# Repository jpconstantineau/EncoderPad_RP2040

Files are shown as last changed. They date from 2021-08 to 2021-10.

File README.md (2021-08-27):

# EncoderPad RP2040

### What is the EncoderPad RP2040?

The EncoderPad RP2040 is a Video Editing Macropad with a 60mm Encoder Wheel. This encoder is made of metal and feels like it will last forever. The EncoderPad uses 9 mechanical switches (Cherry MX type).  The keys are hot-swap socketed and have an individual underglow RGB LED which can be turned on.

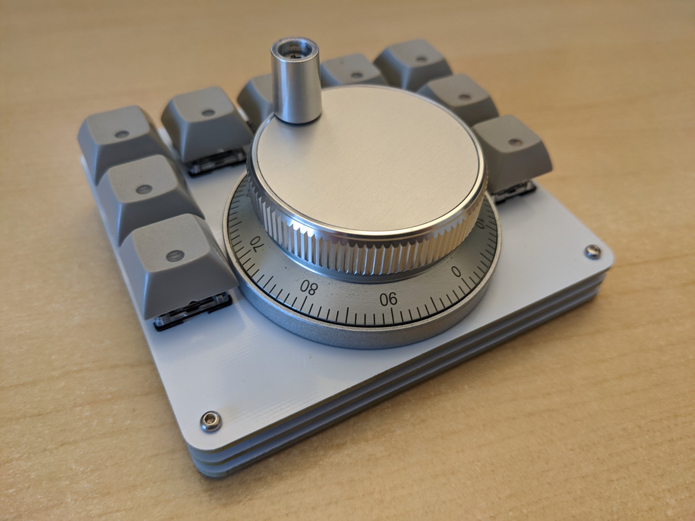
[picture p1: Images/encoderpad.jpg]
EncoderPad


### How do I build it?

You don't need many tools to build it!  
* Install the rotary encoder on the top plate. (there are nuts at the back)
* Press the switches through the top plate
* Align the key switch pins with their sockets and press them in, 
* Attach the wires for the rotary encoder
* Screw in the top/bottom screws through the standoffs
* Install the keycaps
* Install the adhesive rubber bump ons as feet.

### How do I program it?

The Encoder Pad can be programmed with CircuitPython.  To get started, get the latest download from the official [CircuitPython.org](https://circuitpython.org/) site, put the RP2040 in  booloader mode by pressing "reset" while pressing the "boot" button and drag/drop in the UF2 file you just downloaded. You are now ready to program it! No build tools required on your computer!

Notes: 
* CircuitPython is licensed under the [MIT License](https://github.com/adafruit/circuitpython/blob/main/LICENSE).
* Default Firmware for the EncoderPad is based on the [MACROPAD Hoykeys](https://learn.adafruit.com/macropad-hotkeys) example for the [Adafruit Macropad RP2040](https://learn.adafruit.com/adafruit-macropad-rp2040) which is part of the [Adafruit Learning System Guides](https://learn.adafruit.com/), licensed under the [MIT License](https://github.com/adafruit/Adafruit_Learning_System_Guides/blob/main/LICENSE).
* Default firmware is **MIT** licensed.

### Hardware License

Design of the EncoderPad_RP2040 is licensed under **CERN Open Hardware Licence Version 2 - Weakly Reciprocal**

See license.txt for more details. See this [FAQ](https://ohwr.org/project/cernohl/wikis/faq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) for more information on this license.

### Licenses from reference material and libraries

|  Item  | Description | Source  | License  |
|----|---- | :-----  | :--- |
| RP2040 Hardware Design Guide  | RP2040 Documentation (for reference) | [link](https://datasheets.raspberrypi.org/rp2040/hardware-design-with-rp2040.pdf) | CC BY-ND |
| RP2040 Minimal Design Example | Kicad Project | [link](https://datasheets.raspberrypi.org/rp2040/Minimal-KiCAD.zip) | 3-Clause BSD (considered as source code included as part of documentation) |
| kicad libraries | Core libraries from Kicad | [link](https://www.kicad.org/libraries/license/) | CC-BY-SA 4.0 (with exception)|
| kicad libraries | switch symbols and footprints | [link](https://github.com/sszczep/kicad-libraries)| MIT | 

### openmoko-usb-oui application details

[USB PID Request](https://github.com/openmoko/openmoko-usb-oui)

1. (done) Have a README[.txt|.md] file describing which part is under which license this will help to quickly identify the project's license, particularly when several licenses are combined, or your are using libraries under other licenses. Also make sure the combination is allowed by the individual licenses.
2. (done) Include all full text licenses in a LICENSE[.txt] file
3. (done) Include a copyright notice in the schematic sheet(s), including author and date this will determine who the copyright holder is, and when the copyright will expire.
4. (done) Include the license name in the schematic sheet(s) this becomes important when different license are combined, and parts of the project, or libraries, are under different licenses
5. (done) Include all schematic symbols and board footprint libraries in the project without that the project can't be seen as complete. Also ensure their license is compatible.
66. (done) Export the schematic capture as pdf, and board layout as gerber+NC drill [and other fabrication output] files - not every user can, or wants, to install the EDA suite you are using. This is even more important if in the future this suite stops supporting the current format. If you don't want to mix the fabrication output with the source files, have a general project page pointing to the source files and fabrication output.

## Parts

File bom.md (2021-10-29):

### Bill of Materials

* EncoderPad RP2040 PCB
* Bottom Plate
* Top/Switch Plate
* 9 MX Switches and keycaps
* 60mm pulse generator (Encoder with 4 connections at the back)
* 4 M-F dupont cables
* 3 12mm m2 brass standoffs
* 2 10mm m2 brass standoffs
* 2 8mm m2 brass standoffs
* 14 4mm m2 screws
* 4 rubber bump ons

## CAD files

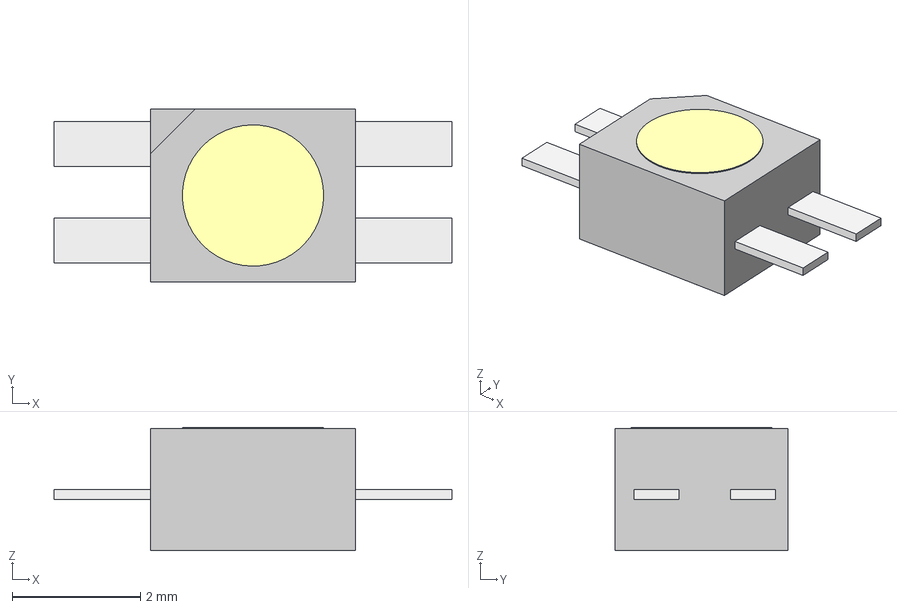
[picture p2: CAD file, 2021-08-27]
PCB-design/models/LTST-A683CEGBW.step
6.20 x 2.70 x 1.92 mm

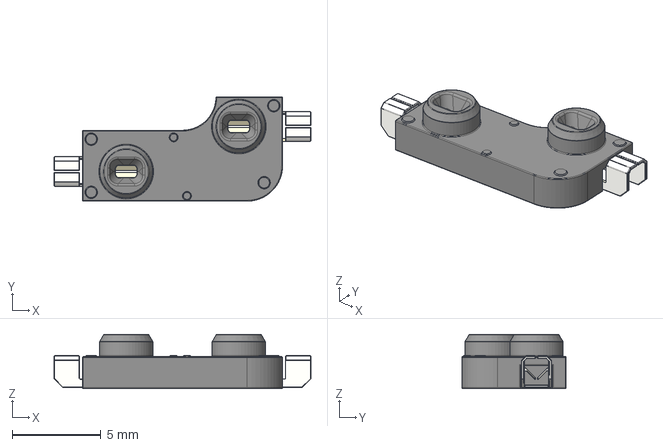
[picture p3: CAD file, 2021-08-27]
PCB-design/models/KailhSocket.stp
14.5 x 5.89 x 3.05 mm

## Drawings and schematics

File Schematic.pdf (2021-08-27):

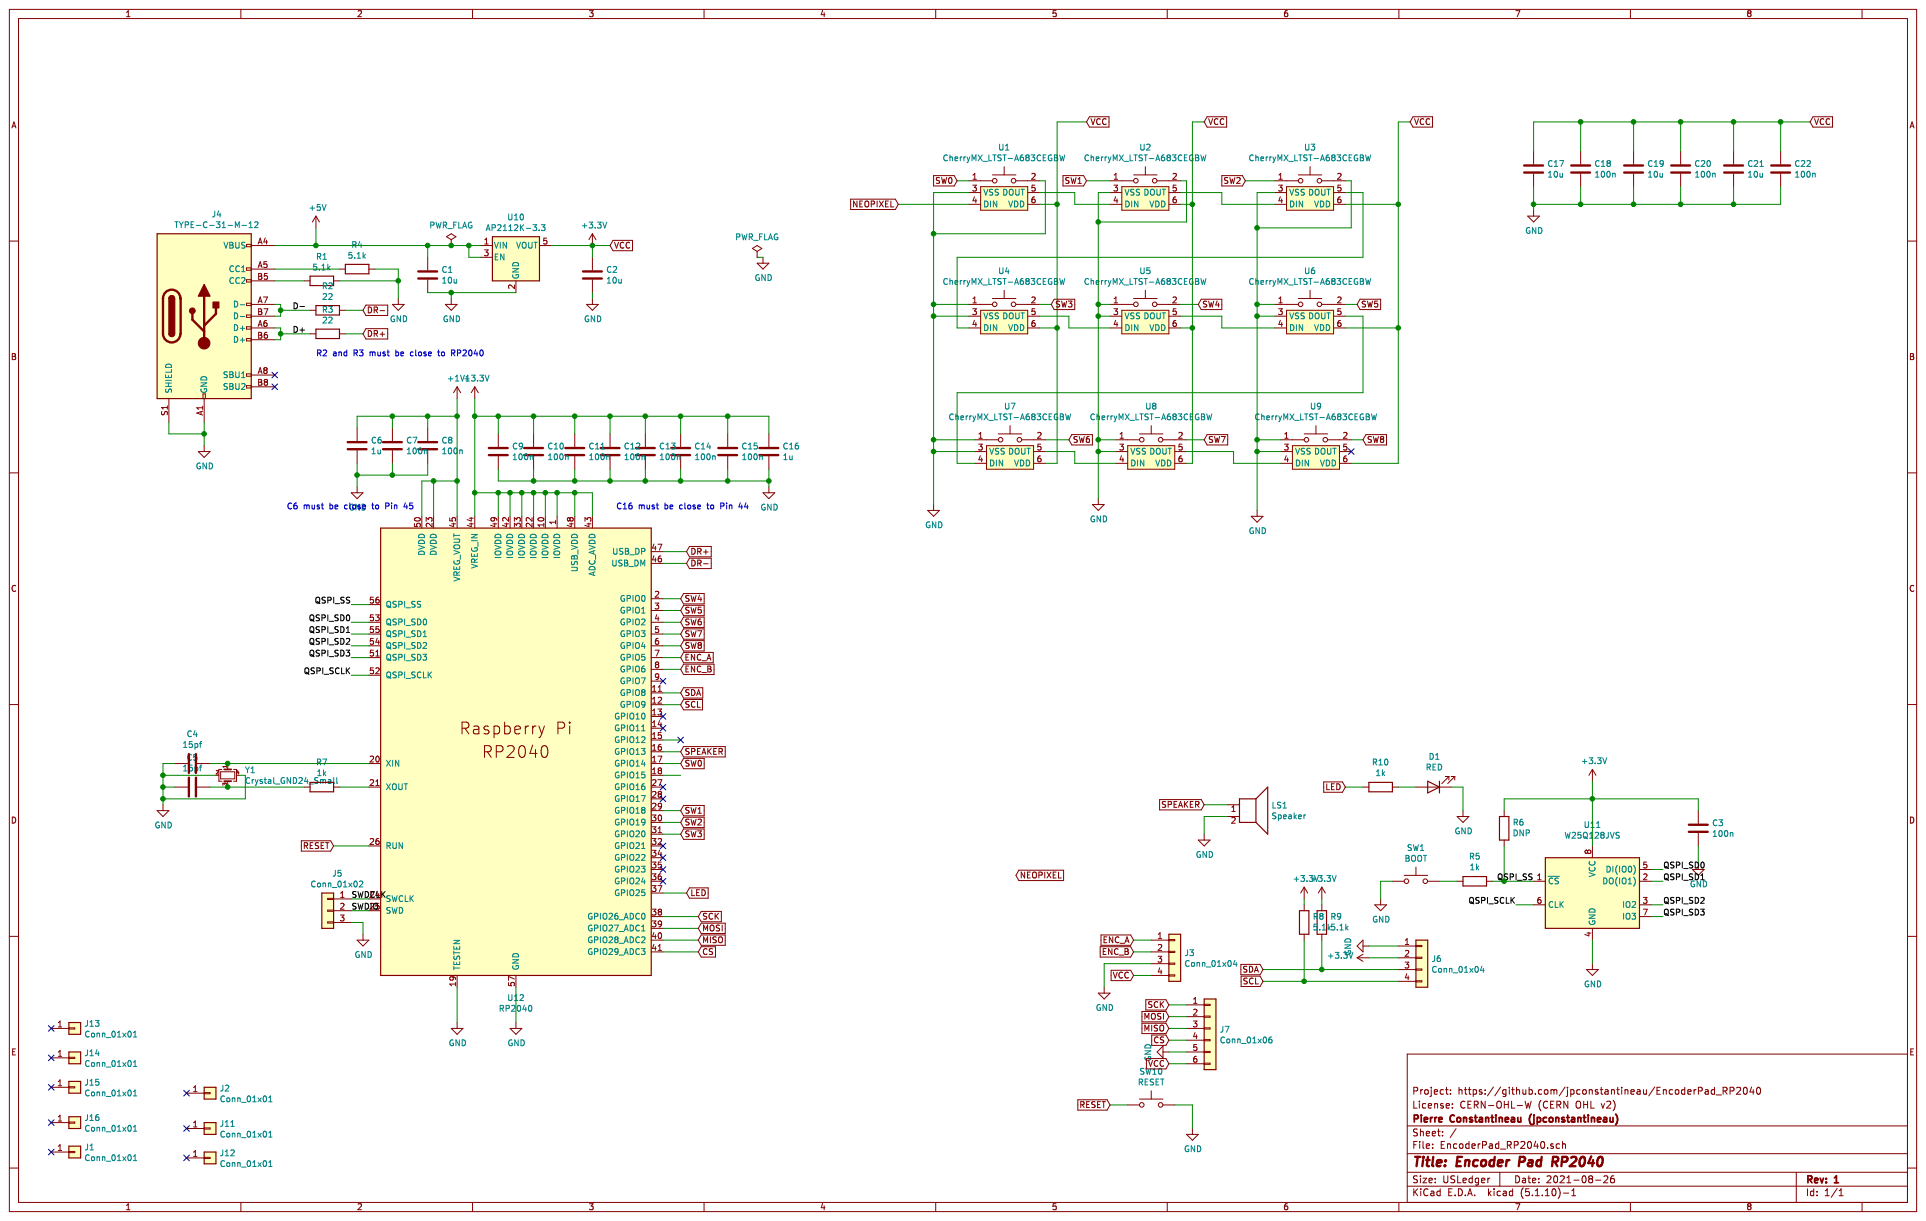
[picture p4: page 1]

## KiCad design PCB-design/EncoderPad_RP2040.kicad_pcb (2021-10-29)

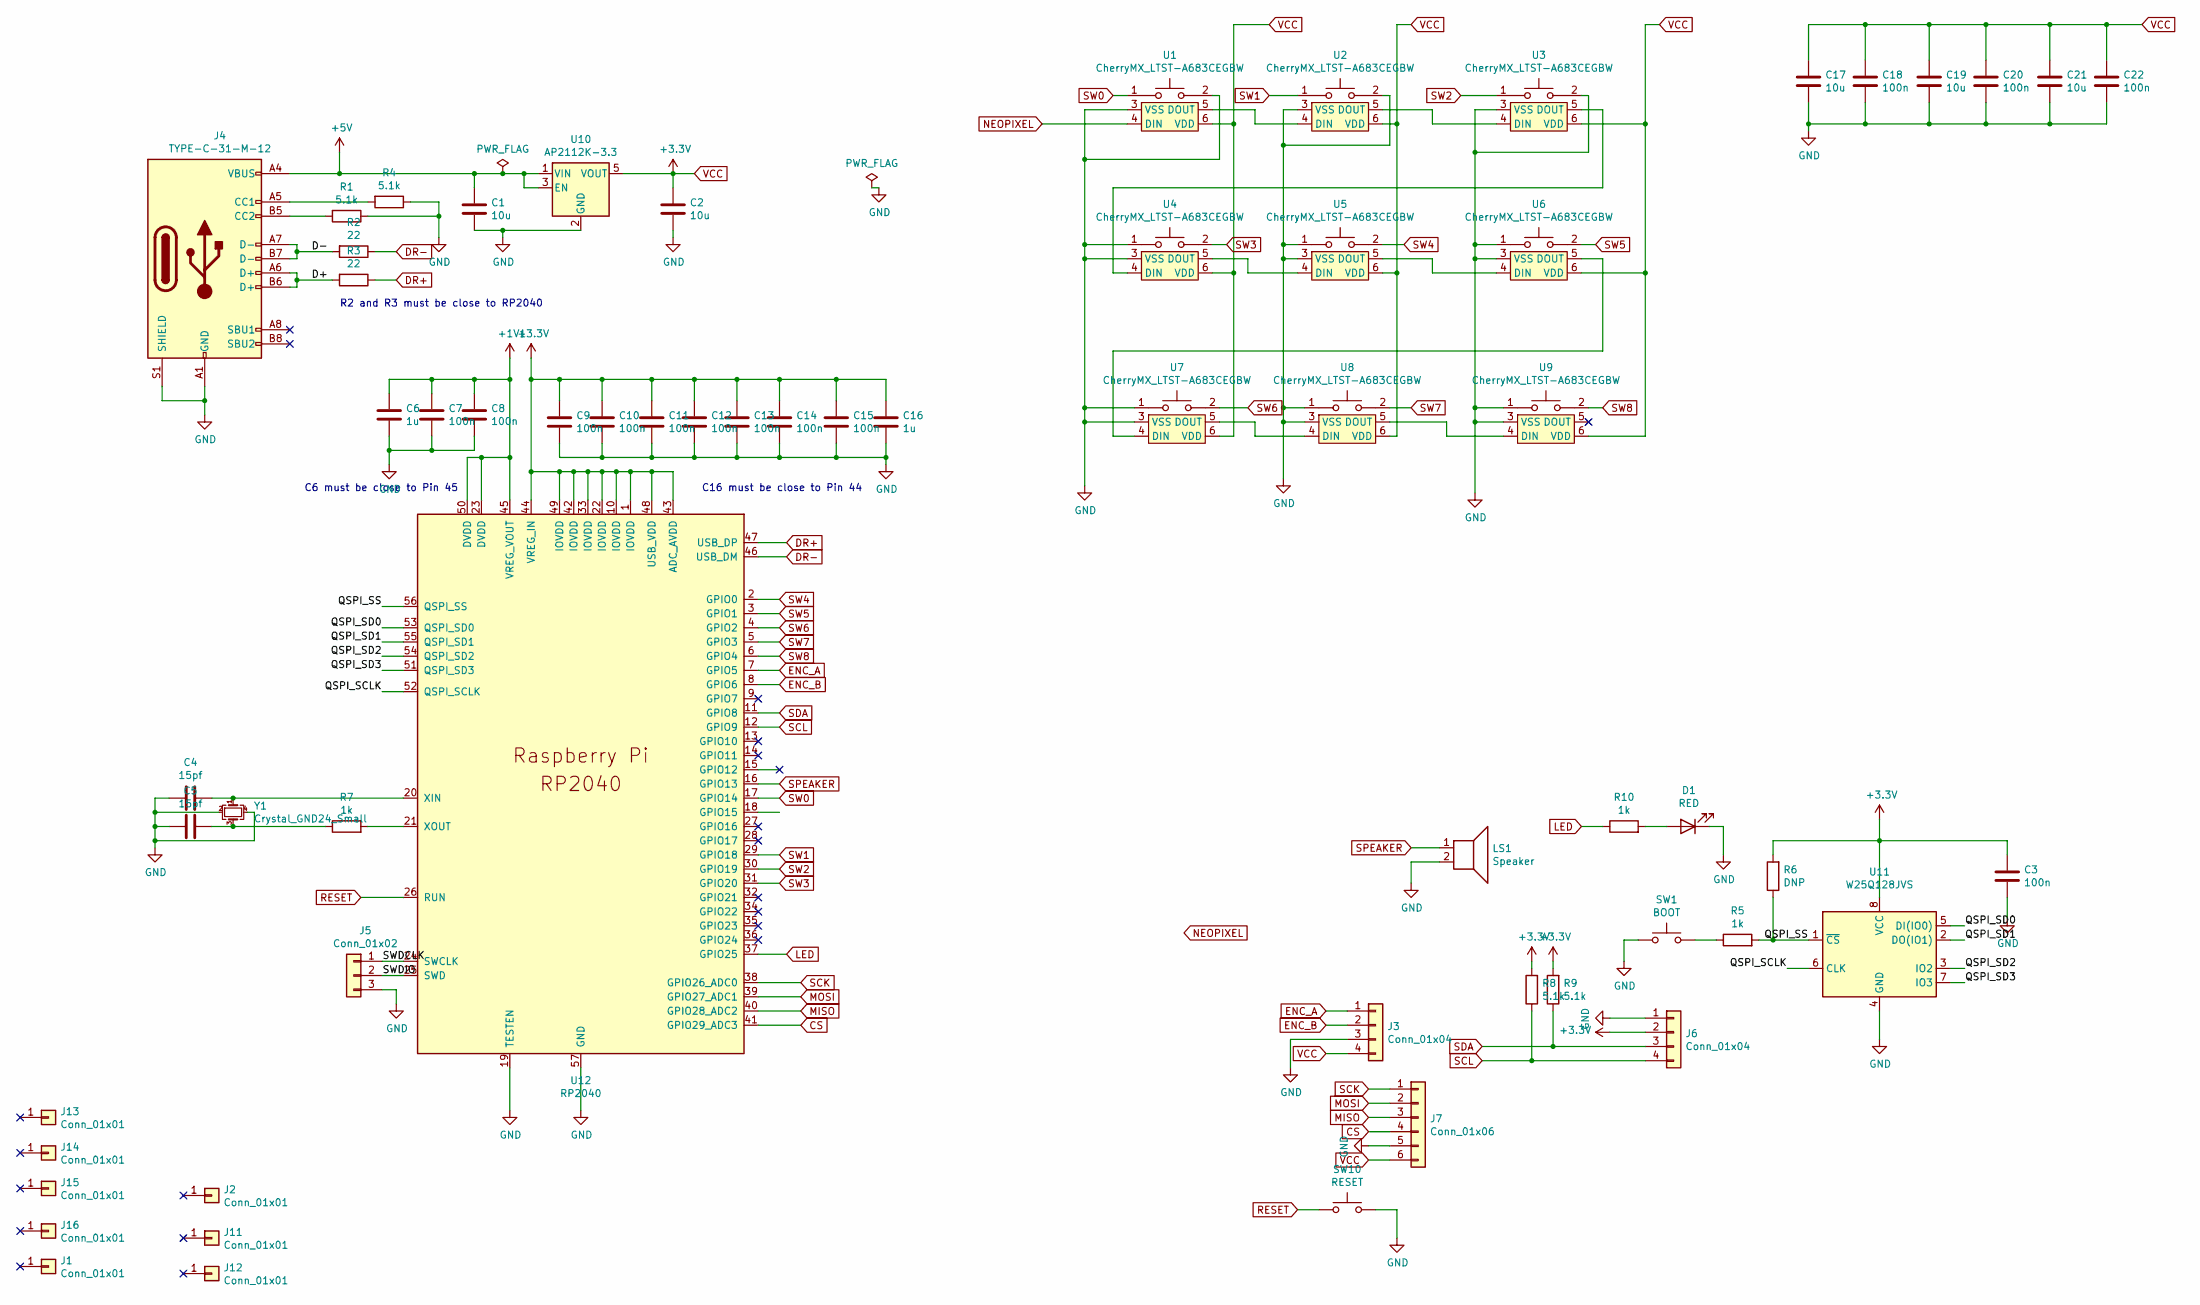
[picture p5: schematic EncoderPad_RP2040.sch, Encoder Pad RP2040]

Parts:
C1, C2, C17, C19, C21: 10u; C_0603_1608Metric; LCSC C15850
C3, C7, C8, C9, C10, C11, C12, C13, C14, C15, C18, C20, C22: 100n; C_0603_1608Metric; LCSC C14663
C4, C5: 15pf; C_0603_1608Metric; LCSC C1644
C6, C16: 1u; C_0603_1608Metric; LCSC C15849
D1: RED; LED_0603_1608Metric
J1: Conn_01x01; CNC_Encoder
J2, J11, J12, J13, J14, J15, J16: Conn_01x01; MountingHole_3.5mm
J3: Conn_01x04; PinHeader_1x04_P2.54mm_Horizontal
J4: TYPE-C-31-M-12; USB_C_Receptacle_HRO_TYPE-C-31-M-12; LCSC C165948
J5: Conn_01x02; PinHeader_1x03_P2.54mm_Vertical
J6: Conn_01x04; PinHeader_1x04_P2.54mm_Vertical
J7: Conn_01x06; PinHeader_1x06_P1.27mm_Vertical
LS1: Speaker; AST1109MLTRQ
R1, R4, R8, R9: 5.1k; R_0603_1608Metric; LCSC C23186
R2, R3: 22; R_0603_1608Metric; LCSC C23345
R5, R7, R10: 1k; R_0603_1608Metric; LCSC C21190
R6: DNP; R_0603_1608Metric
SW1: BOOT; SW_TACT_ALPS_SKQGABE010
SW10: RESET; SW_TACT_ALPS_SKQGABE010
U1, U2, U3, U4, U5, U6, U7, U8, U9: CherryMX_LTST-A683CEGBW; CherryMX_1.00u_PCB_KailhSocket_LTST-A683CEGBW-Rotated
U10: AP2112K-3.3; SOT-23-5
U11: W25Q128JVS; SOIC-8_5.23x5.23mm_P1.27mm; LCSC C97521
U12: RP2040; RP2040-QFN-56
Y1: Crystal_GND24_Small; Crystal_SMD_3225-4Pin_3.2x2.5mm; LCSC C97242

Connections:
+1V1: C6.1, C7.1, C8.1, U12.23 (DVDD), U12.45 (VREG_VOUT), U12.50 (DVDD)
+5V: C1.1, J4.A4 (VBUS), J4.A9 (VBUS), J4.B4 (VBUS), J4.B9 (VBUS), U10.1 (VIN), U10.3 (EN)
/D+: J4.A6 (D+), J4.B6 (D+), R3.2
/D-: J4.A7 (D-), J4.B7 (D-), R2.2
/QSPI_SCLK: U11.6 (CLK), U12.52 (QSPI_SCLK)
/QSPI_SD0: U11.5 (DI(IO0)), U12.53 (QSPI_SD0)
/QSPI_SD1: U11.2 (DO(IO1)), U12.55 (QSPI_SD1)
/QSPI_SD2: U11.3 (IO2), U12.54 (QSPI_SD2)
/QSPI_SD3: U11.7 (IO3), U12.51 (QSPI_SD3)
/QSPI_SS: R5.2, R6.1, U11.1 (~CS), U12.56 (QSPI_SS)
/SWDCLK: J5.1, U12.24 (SWCLK)
/SWDIO: J5.2, U12.25 (SWD)
CS: J7.4, U12.41 (GPIO29_ADC3)
DR+: R3.1, U12.47 (USB_DP)
DR-: R2.1, U12.46 (USB_DM)
ENC_A: J3.1, U12.7 (GPIO5)
ENC_B: J3.2, U12.8 (GPIO6)
GND: C1.2, C2.2, C3.2, C4.2, C5.2, C6.2, C7.2, C8.2, C9.2, C10.2, C11.2, C12.2, C13.2, C14.2, C15.2, C16.2, C17.2, C18.2, C19.2, C20.2, C21.2, C22.2, D1.1 (K), J3.3, J4.A1 (GND), J4.A12 (GND), J4.B1 (GND), J4.B12 (GND), J4.S1 (SHIELD), J5.3, J6.1, J7.5, LS1.2, R1.1, R4.1, SW1.1, SW10.2, U1.2, U1.3 (VSS), U2.2, U2.3 (VSS), U3.2, U3.3 (VSS), U4.1, U4.3 (VSS), U5.1, U5.3 (VSS), U6.1, U6.3 (VSS), U7.1, U7.3 (VSS), U8.1, U8.3 (VSS), U9.1, U9.3 (VSS), U10.2 (GND), U11.4 (GND), U12.19 (TESTEN), U12.57 (GND), Y1.2, Y1.4
LED: R10.1, U12.37 (GPIO25)
MISO: J7.3, U12.40 (GPIO28_ADC2)
MOSI: J7.2, U12.39 (GPIO27_ADC1)
NEOPIXEL: U1.4 (DIN), U12.18 (GPIO15)
unnamed: C4.1, U12.20 (XIN), Y1.1
unnamed: C5.1, R7.1, Y1.3
unnamed: D1.2 (A), R10.2
unnamed: J4.A5 (CC1), R4.2
unnamed: J4.B5 (CC2), R1.2
unnamed: R5.1, SW1.2
unnamed: R7.2, U12.21 (XOUT)
unnamed: U1.5 (DOUT), U2.4 (DIN)
unnamed: U2.5 (DOUT), U3.4 (DIN)
unnamed: U3.5 (DOUT), U4.4 (DIN)
unnamed: U4.5 (DOUT), U5.4 (DIN)
unnamed: U5.5 (DOUT), U6.4 (DIN)
unnamed: U6.5 (DOUT), U7.4 (DIN)
unnamed: U7.5 (DOUT), U8.4 (DIN)
unnamed: U8.5 (DOUT), U9.4 (DIN)
RESET: SW10.1, U12.26 (RUN)
SCK: J7.1, U12.38 (GPIO26_ADC0)
SCL: J6.4, R8.1, U12.12 (GPIO9)
SDA: J6.3, R9.1, U12.11 (GPIO8)
SPEAKER: LS1.1, U12.16 (GPIO13)
SW0: U1.1, U12.17 (GPIO14)
SW1: U2.1, U12.29 (GPIO18)
SW2: U3.1, U12.30 (GPIO19)
SW3: U4.2, U12.31 (GPIO20)
SW4: U5.2, U12.2 (GPIO0)
SW5: U6.2, U12.3 (GPIO1)
SW6: U7.2, U12.4 (GPIO2)
SW7: U8.2, U12.5 (GPIO3)
SW8: U9.2, U12.6 (GPIO4)
VCC: C2.1, C3.1, C9.1, C10.1, C11.1, C12.1, C13.1, C14.1, C15.1, C16.1, C17.1, C18.1, C19.1, C20.1, C21.1, C22.1, J3.4, J6.2, J7.6, R6.2, R8.2, R9.2, U1.6 (VDD), U2.6 (VDD), U3.6 (VDD), U4.6 (VDD), U5.6 (VDD), U6.6 (VDD), U7.6 (VDD), U8.6 (VDD), U9.6 (VDD), U10.5 (VOUT), U11.8 (VCC), U12.1 (IOVDD), U12.10 (IOVDD), U12.22 (IOVDD), U12.33 (IOVDD), U12.42 (IOVDD), U12.43 (ADC_AVDD), U12.44 (VREG_IN), U12.48 (USB_VDD), U12.49 (IOVDD)

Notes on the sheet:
R2 and R3 must be close to RP2040
C6 must be close to Pin 45
C16 must be close to Pin 44

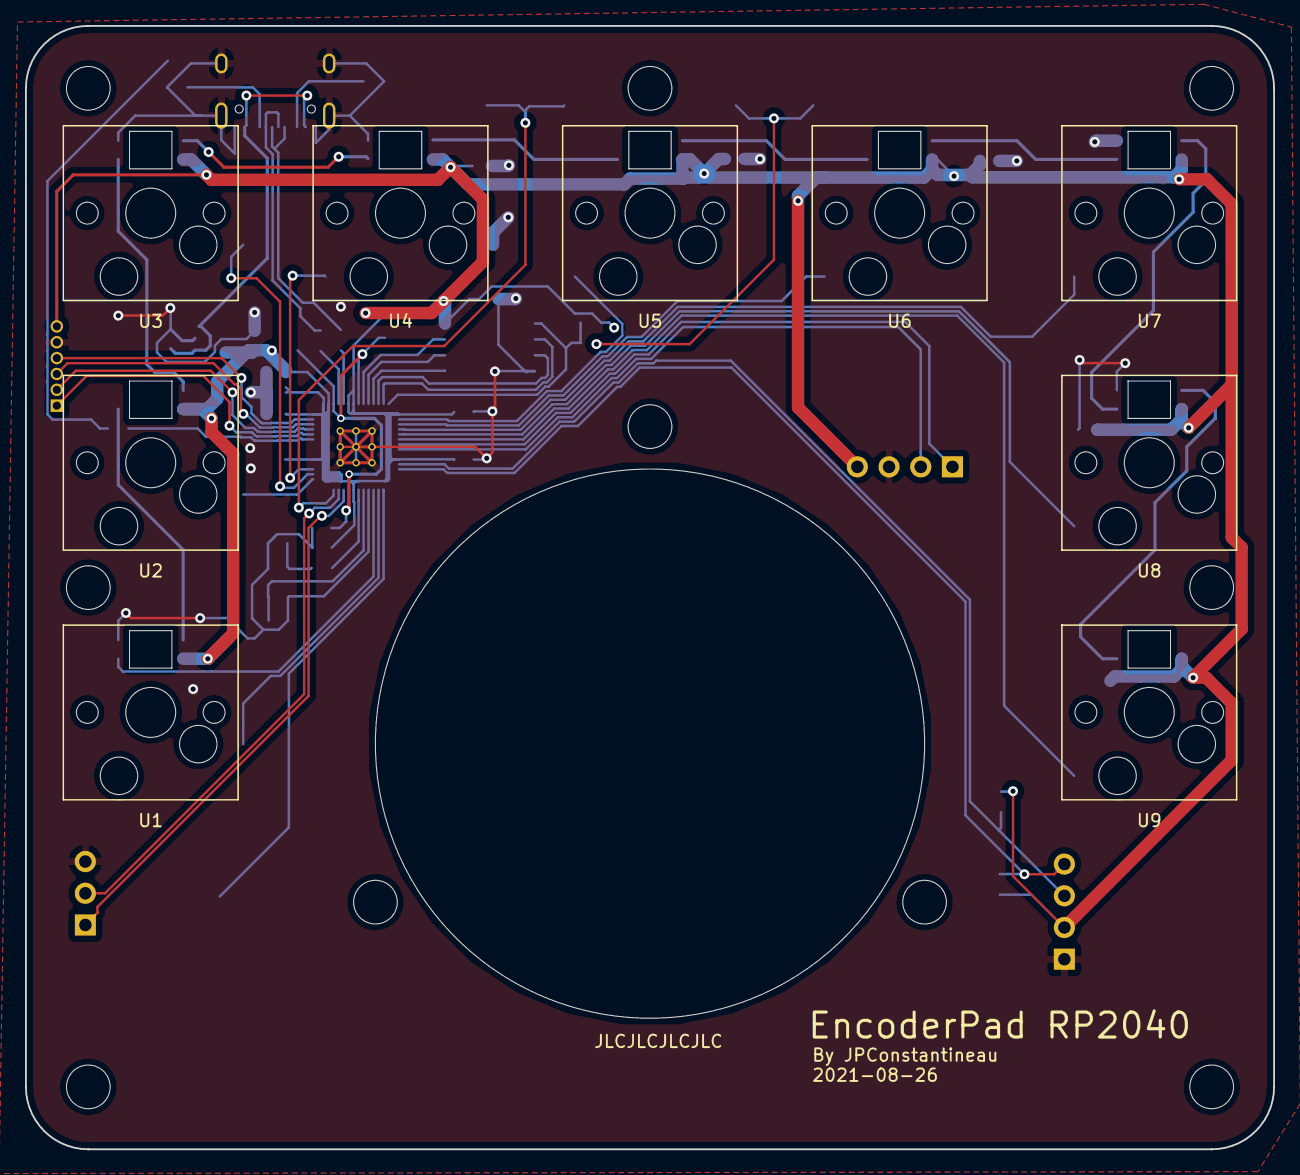
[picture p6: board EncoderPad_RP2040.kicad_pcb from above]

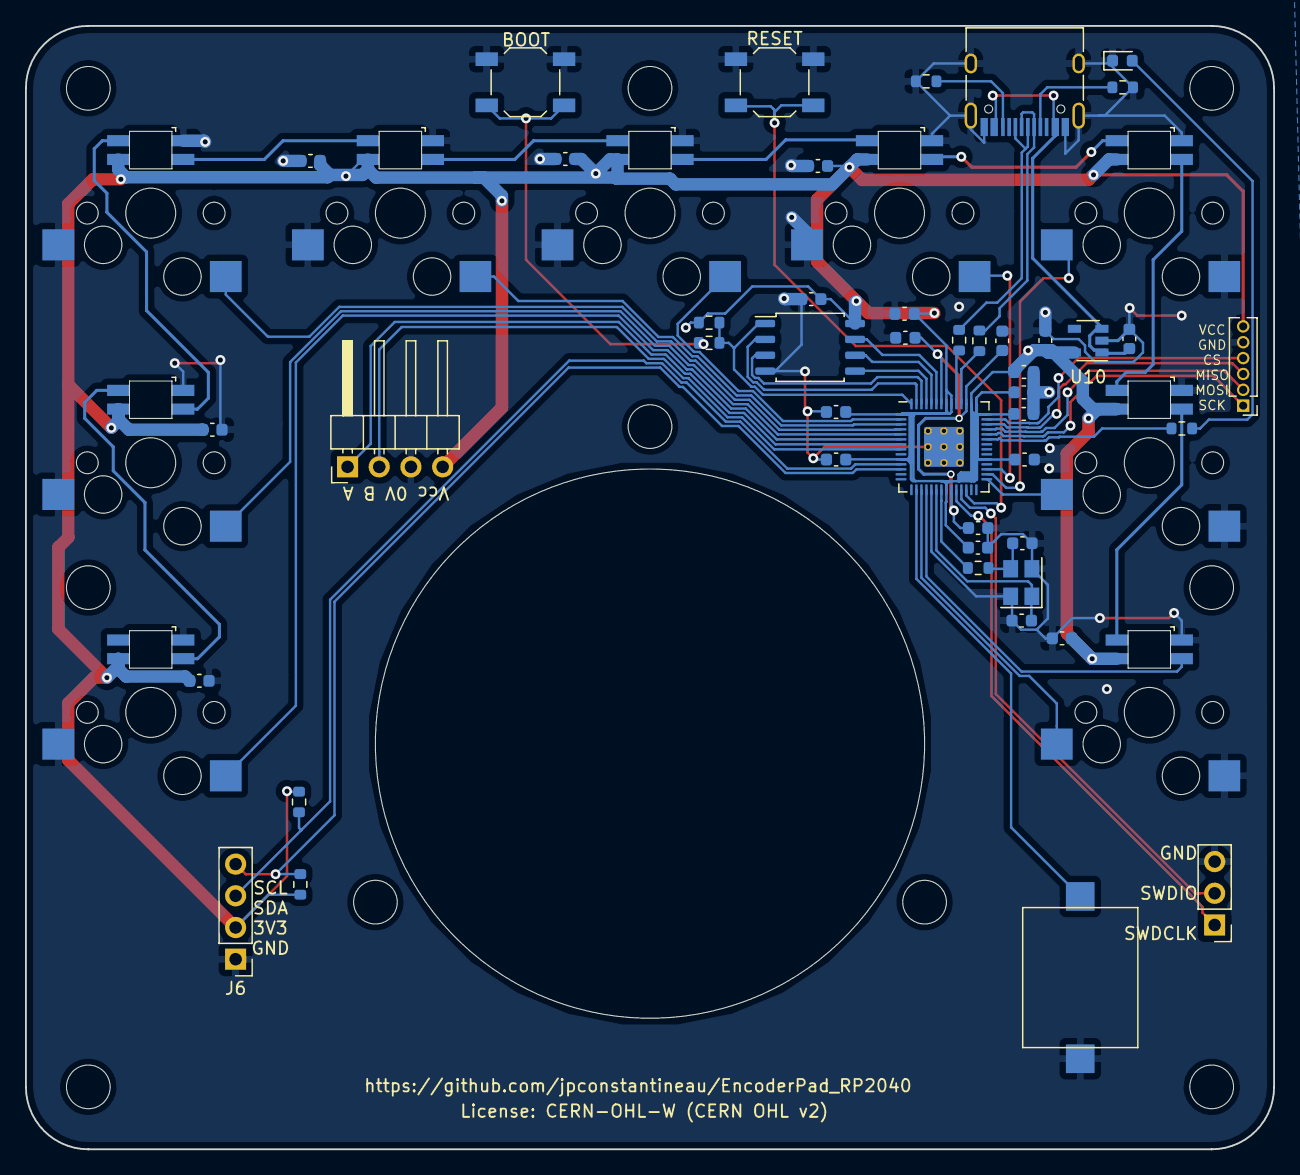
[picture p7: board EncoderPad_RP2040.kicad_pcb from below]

Board: 2 copper layers, 100.0 x 90.0 mm, 62 parts (45 on the bottom side), 52 nets.

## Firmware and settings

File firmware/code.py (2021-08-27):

# SPDX-FileCopyrightText: 2021 Pierre Constantineau
# SPDX-License-Identifier: MIT

# This code is currently a work in progress for the prototype hardware
# and is not expected to work as-is on the final hardware
# firmware will be updated.

#pylint: disable = line-too-long
import time
import alarm
import board
import rotaryio
import keypad
import usb_hid
import pwmio
from adafruit_hid.keyboard import Keyboard
from adafruit_hid.keyboard_layout_us import KeyboardLayoutUS
from pykey.keycode import PK_Keycode as KC
import pykey.lights as lights

################################################################
# init board's User Input (keys, buttons, encoders)
# replace with your own pins and stuff
################################################################
# -------------------------------------------
# Hardware definition: Switch Matrix Setup.
# -------------------------------------------
keys = keypad.KeyMatrix(
    row_pins=(board.P0_06, board.P1_13, board.P0_28),
    column_pins=(board.P0_09, board.P0_13,board.P1_06),
    columns_to_anodes=False,
)

# -------------------------------------------
# Hardware definition: Key Switch Setup.
# -------------------------------------------
buttons = None

# -------------------------------------------
# Hardware definition: rotary encoder
# -------------------------------------------
encoder = rotaryio.IncrementalEncoder(board.P0_26, board.P0_30)


################################################################
# init board's LEDs for visual output
# replace with your own pins and stuff
################################################################
# -------------------------------------------
# Hardware definition: GPIO where Neopixel (RGB LED) is connected.
# -------------------------------------------
pixel_pin = None
num_pixels = 0

# -------------------------------------------
# Hardware definition: LED Matrix
# -------------------------------------------
leds = lights.LEDMatrix((board.P0_08,board.P0_02,board.P0_03),(board.P0_24,board.P0_20,board.P0_10),True)
leds.reset_leds()


# -------------------------------------------
# Hardware definition: audio hardware
# -------------------------------------------
buzzer = pwmio.PWMOut(board.P0_29, variable_frequency=True)
buzzer.frequency = 440
OFF = 0
ON = 2**15
not_sleeping = True


################################################################
# Initialize common variables
# No need to replace things
################################################################
keyboard = Keyboard(usb_hid.devices)
keyboard_layout = KeyboardLayoutUS(keyboard)
last_position = 0
layer = 0



keymap = ((KC.A,KC.B,KC.C,KC.D,KC.E,KC.F,KC.G,KC.H,KC.I),
        (KC.A,KC.B,KC.C,KC.D,KC.E,KC.F,KC.G,KC.H,KC.I))


encoder_map = ((KC.LEFT,KC.RIGHT),
                (KC.LEFT, KC.RIGHT))

################################################################
# DONE SETTING UP 
################################################################
# End of Setup: Lets play some Music to let the user we are ready
buzzer.duty_cycle = ON
buzzer.frequency = 440
time.sleep(0.05)
buzzer.frequency = 880
time.sleep(0.05)
buzzer.frequency = 1660
time.sleep(0.05)
buzzer.duty_cycle = OFF

################################################################
# loop-y-loop
################################################################
while not_sleeping:
    key_event = keys.events.get()
    if key_event:
        key = keymap[layer][key_event.key_number]
        if key_event.pressed:
            keyboard.press(key)
            leds.led_ON(key_event.key_number)
        else:
            keyboard.release(key)

    position = encoder.position
    if position != last_position:
        diff=position-last_position
        if diff>0:
            keyboard.send(encoder_map[layer][0])
        else:
            keyboard.send(encoder_map[layer][1])
    last_position = position
    time.sleep(0.002)
# if we end up here, the program will end with a short tune...
buzzer.duty_cycle = ON
buzzer.frequency = 1660
time.sleep(0.05)
buzzer.frequency = 880
time.sleep(0.05)
buzzer.frequency = 440
time.sleep(0.05)
buzzer.duty_cycle = OFF

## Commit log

2021-08-27 added WIP prototype firmware
2021-10-29 adding BOM - closes #1
    [EncoderPad_RP2040.kicad_pcb]

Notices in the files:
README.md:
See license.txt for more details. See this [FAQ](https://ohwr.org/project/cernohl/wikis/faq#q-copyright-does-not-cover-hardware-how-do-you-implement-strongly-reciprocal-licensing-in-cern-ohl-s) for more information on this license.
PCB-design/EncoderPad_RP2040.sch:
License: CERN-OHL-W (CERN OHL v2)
